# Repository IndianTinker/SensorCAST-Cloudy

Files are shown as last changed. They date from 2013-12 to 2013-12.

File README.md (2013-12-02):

SensorCAST-Cloudy
=================

The Web Connected Weather Logger based on GR-Sakura Board.
Contains the corel draw file for laser cutting the enclosure
Contains the C code and all the required board layouts and schematics

For any queries you can email me at indiantinker[at]gmail[dot]com

The working project video is :
http://www.youtube.com/watch?v=amBn-kbNLqY

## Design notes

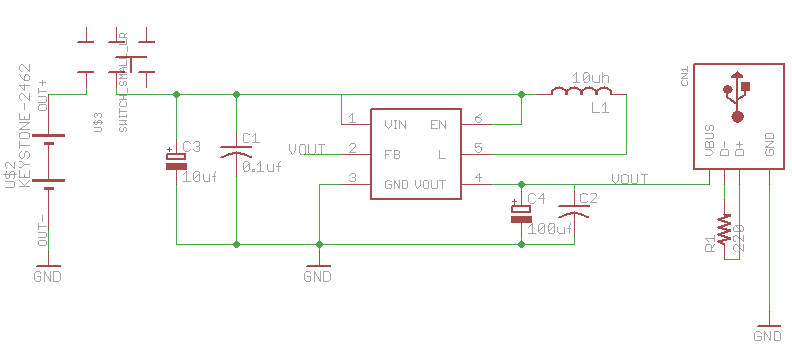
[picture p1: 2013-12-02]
boost.png

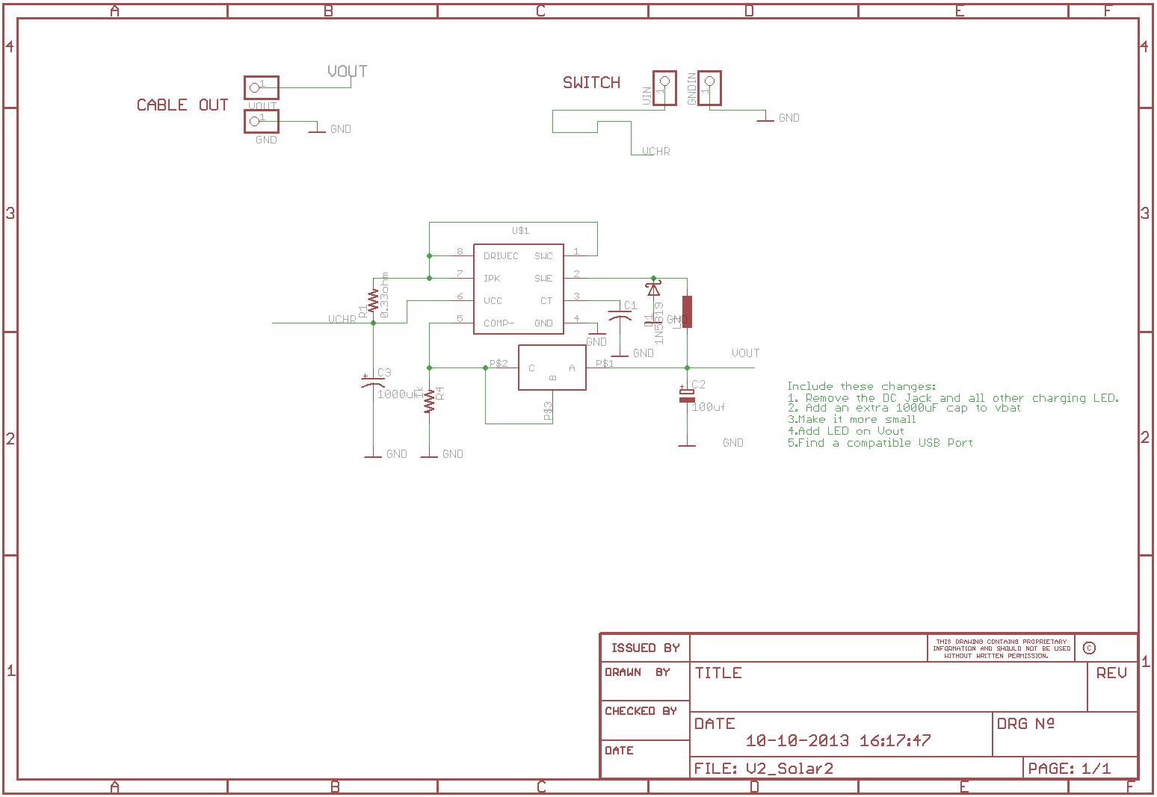
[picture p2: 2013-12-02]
buckss.png

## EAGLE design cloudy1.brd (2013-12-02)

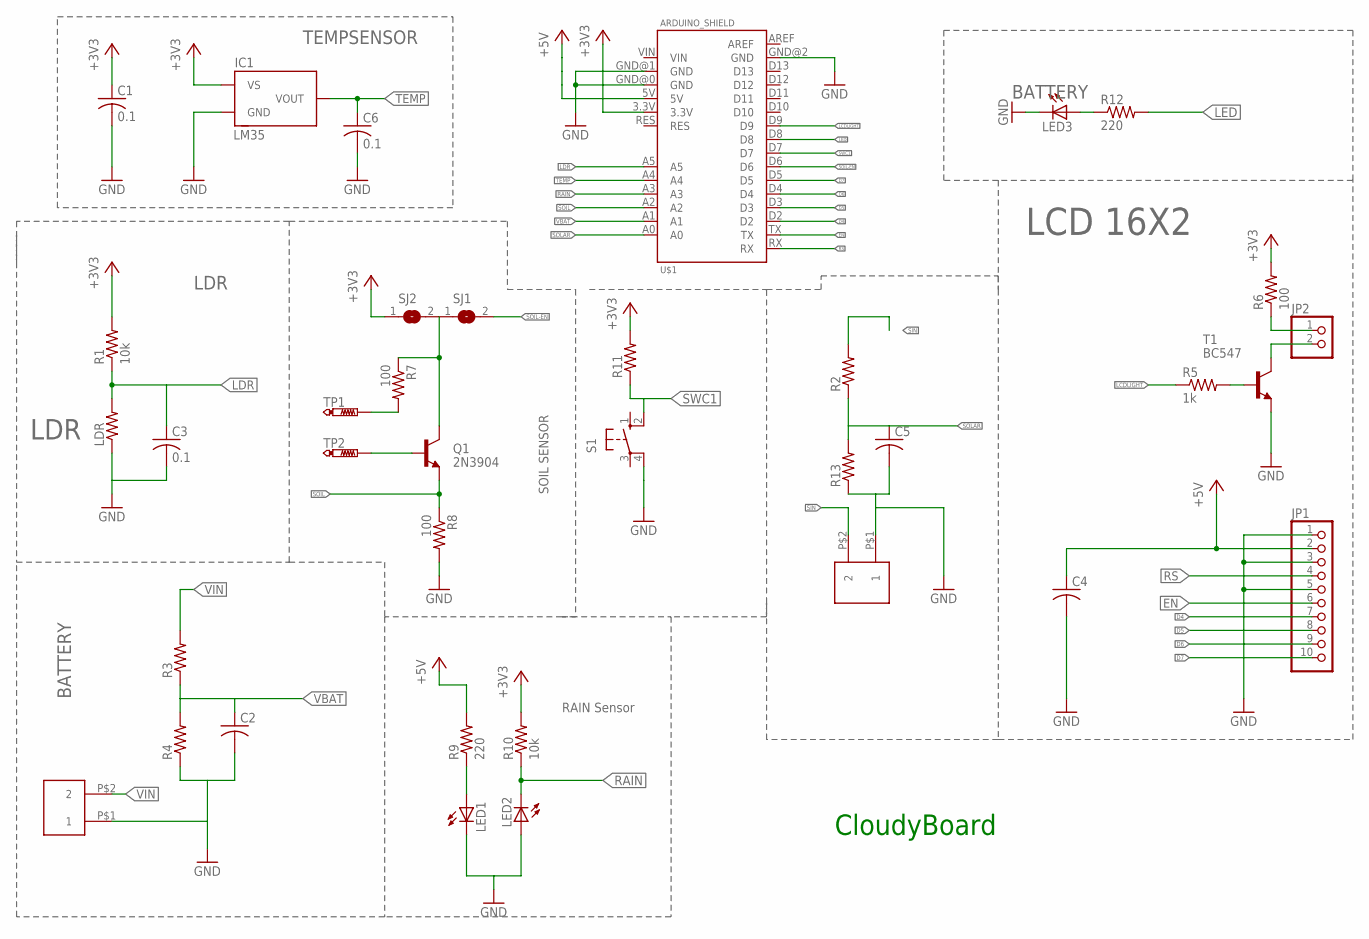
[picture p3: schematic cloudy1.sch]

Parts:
C1, C3, C6: 0.1; C0805
C2, C4, C5: C-USC0805; C0805
IC1: LM35; TO92
JP1: PINHD-1X10; 1X10
JP2: PINHD-1X2; 1X02
LDR: R-US_0204/5; 0204/5
LED1, LED2, LED3: LED5MM
Q1: 2N3904; TO92
R1, R10: 10k; 0204/7
R2, R3, R4, R13: R-US_0204/7; 0204/7
R5: 1k; 0204/7
R6: 100; 0204/7
R7, R8: 100; R0805
R9, R12: 220; 0204/7
R11: R-US_0207/10; 0207/10
S1: 10-XX; B3F-10XX
SJ1, SJ2: SJ
T1: BC547; TO92
TP1, TP2: PTR1TP19SQ; TP19SQ
U$1: ARDUINO_SHIELD
U$2, U$3: POWER_TERMINAL; POWER_TERMINAL_2

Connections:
+3V3: C1.1, IC1.VS, R1.2, R6.2, R10.2, R11.2, SJ2.1, U$1.3.3V
+5V: C4.1, JP1.2, R9.2, U$1.5V
D4: JP1.7, U$1.D2
D5: JP1.8, U$1.D3
D6: JP1.9, U$1.D4
D7: JP1.10, U$1.D5
EN: JP1.6, U$1.TX
GND: C1.2, C2.2, C3.2, C4.2, C5.2, C6.2, IC1.GND, JP1.1, JP1.3, JP1.5, LDR.1, LED1.K (C), LED2.A, LED3.K (C), R4.1, R8.2, R13.1, S1.4 (P1), T1.1 (E), U$1.GND@0 (GND), U$1.GND@1 (GND), U$1.GND@2 (GND), U$2.P$1 (1), U$3.P$1 (1)
LCDLIGHT: R5.1, U$1.D9
LDR: C3.1, LDR.2, R1.1, U$1.A5
LED: R12.2, U$1.D8
unnamed: JP2.1, R6.1
unnamed: JP2.2, T1.3 (C)
unnamed: R5.2, T1.2 (B)
unnamed: Q1.2 (B), TP2.TP
unnamed: R7.2, TP1.TP
unnamed: Q1.1 (C), R7.1, SJ1.1, SJ2.2
unnamed: LED1.A, R9.1
unnamed: LED3.A, R12.1
RAIN: LED2.K (C), R10.1, U$1.A3
RS: JP1.4, U$1.RX
SIN: R2.2, U$3.P$2 (2)
SOIL: Q1.3 (E), R8.1, U$1.A2
SOIL-EN: SJ1.2, U$1.D6
SOLAR: C5.1, R2.1, R13.2, U$1.A0
SWC1: R11.1, S1.2 (S1), U$1.D7
TEMP: C6.1, IC1.VOUT, U$1.A4
VBAT: C2.1, R3.1, R4.2, U$1.A1
VIN: R3.2, U$2.P$2 (2)

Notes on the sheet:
LDR
LCD 16X2
TEMPSENSOR
BATTERY
SOIL SENSOR
RAIN Sensor
CloudyBoard

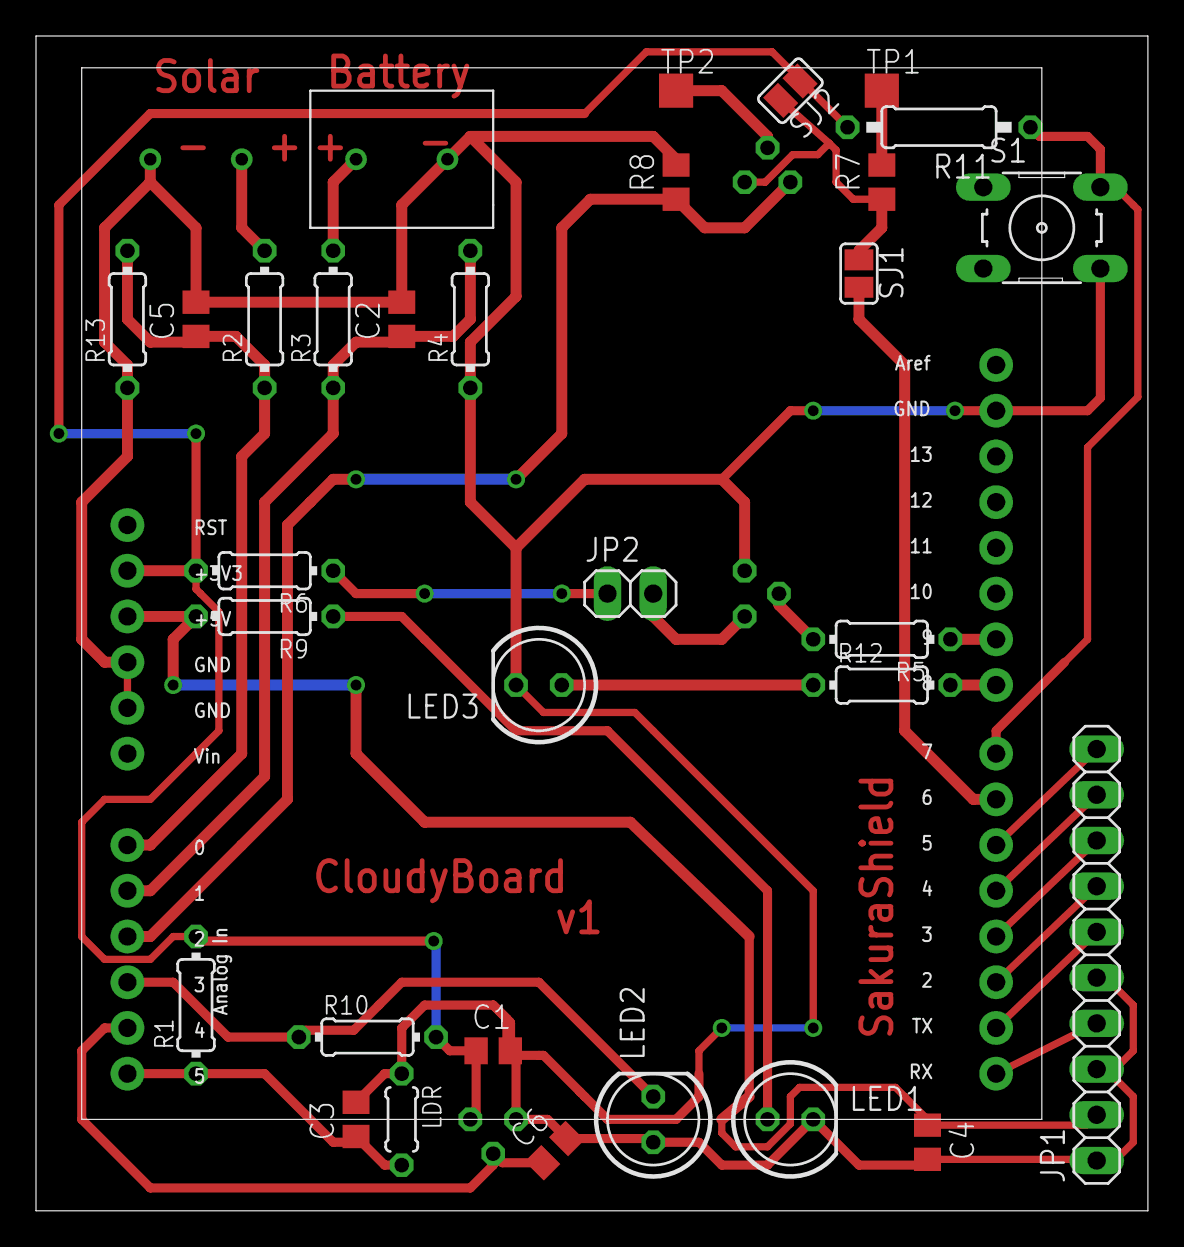
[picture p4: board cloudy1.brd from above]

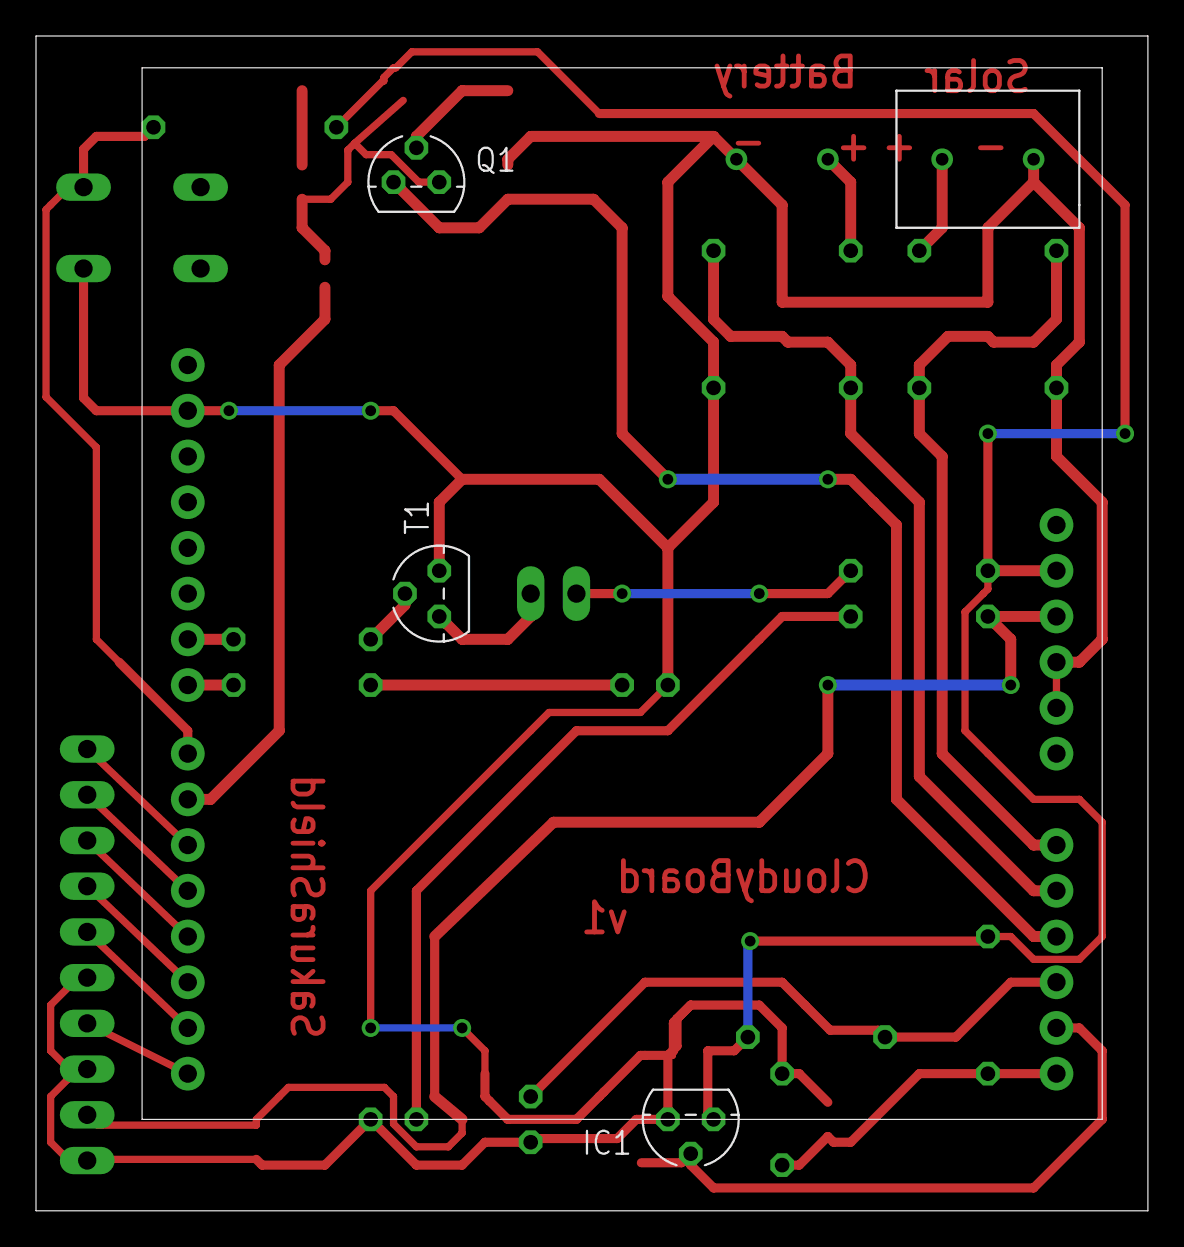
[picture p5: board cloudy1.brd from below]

Board: 2 copper layers, 61.8 x 65.3 mm, 36 parts (4 on the bottom side), 29 nets.

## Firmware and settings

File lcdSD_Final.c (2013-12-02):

#include <rxduino.h>
#include <Liquidcrystal.h>
#include <sdmmc.h>
SDMMC mySD;
LiquidCrystal lcd (0, 1,2, 3, 4,5); //Rs,EN,D4,D5,D6,D7
#define led 8
#define lcdled 9
#define soils 6
int count=0;
int ldr =0;
float temp=0.0;
float solar=0.0;
float battery=0.0;
int soil=0;
void scanSensors()
{
ldr=analogRead(5);
temp=analogRead(4);
temp*=0.488;
solar=analogRead(0);
solar*=0.0384;
battery=analogRead(1);
battery*=0.0201;
digitalWrite(soils,1);
delay(1000);
soil=analogRead(2);
delay(1000);
digitalWrite(soils,0);
}
void disp()
{
scanSensors();
lcd.clear();
lcd.print ("Light intensity");
if (ldr>550)
{
digitalWrite(9,1);
}
else
{
digitalWrite(9,0);
}
lcd.setCursor(0,1);
lcd.print(ldr);
delay(2000);
lcd.clear();
lcd.setCursor(0,0);
lcd.print("Temperature");
lcd.setCursor(0,1);
lcd.print(temp);
delay(2000);

lcd.clear();
lcd.setCursor(0,0);
lcd.print("Solar Panel V");
lcd.setCursor(0,1);
lcd.print(solar);
delay(2000);

lcd.clear();
lcd.setCursor(0,0);
lcd.print("Battery V");
lcd.setCursor(0,1);
lcd.print(battery);
delay(2000);

lcd.clear();
lcd.setCursor(0,0);
lcd.print("Soil Moisture");
lcd.setCursor(0,1);
lcd.print(soil);
delay(2000);

digitalWrite(8,1);
delay(100);
digitalWrite(8,0);
delay(100);
}
void writeSD()
{
digitalWrite (PIN_LED2, 1);
File myFile = mySD.open ("t_write.txt", FILE_WRITE);
    if (myFile == false)
    {
        lcd.clear();
        lcd.print("Access Failed");
        digitalWrite (PIN_LED3, 1);
        while (1) {
                   }
    }

    // Write
    //Serial.println ("Success to access MMC");
    //digitalWrite(PIN_LED2,1);
 
   myFile.print(ldr);
   myFile.print(',');
   myFile.print(temp);
   myFile.print(',');
   myFile.print(solar);
   myFile.print(',');
   myFile.print(battery);
   myFile.print(',');
   myFile.print(soil);
   myFile.println ();
   myFile.close ();
   delay(500);
   digitalWrite(PIN_LED2,0);
}
void setup()
{       lcd.begin (16,2);
        pinMode(PIN_LED0,OUTPUT);
        pinMode(PIN_LED1,OUTPUT);
        pinMode(PIN_LED2,OUTPUT);
        pinMode(PIN_LED3,OUTPUT);
        pinMode(6,OUTPUT);
        pinMode(7,OUTPUT);
        pinMode(8,OUTPUT);
        pinMode(9,OUTPUT);   
        digitalWrite(7, 0);
        digitalWrite(9, 0);
        digitalWrite(6, 0);
        digitalWrite(8, 0);
        lcd.print("  CloudY v3.4  ");
        
        // start the Ethernet connection and the server:
       
        mySD.begin ();
        //pinMode ( PIN_SW ,INPUT );
        delay(500);
        digitalWrite(PIN_LED0, 1);                            
}
void loop()
{
disp();
count++;
if(count==5)
{
writeSD();
count=0;
}
}
